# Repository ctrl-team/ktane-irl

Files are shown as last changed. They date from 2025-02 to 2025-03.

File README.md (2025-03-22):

# ktane-irl

## Overview
This project is a real-life adaptation of the game "Keep Talking and Nobody Explodes.".
Modules may use Arduino or different microcontrollers, with each module documented in its own directory.

## Features
* Real-life bomb-defusal gameplay
* Advanced component system

## Software Requirements
- Arduino IDE
- TFT_eSPI library (included in lib/)

## Installation

### 1. Clone the Repository
```sh
git clone https://github.com/ctrl-team/ktane-irl.git
cd ktane-irl
```
### 2. Configure TFT_eSPI
TFT_eSPI requires a proper `User_Setup_Select.h` configuration. Users must manually edit:
```sh
TFT_eSPI/User_Setup_Select.h
```
#### to include:
for main timer board
```cpp
#include "User_Setups/Setup304_RP2040_ILI9341_Waveshare_2_4"
```
for button module
```cpp
#include <User_Setups/Setup305_RP2040_GC9A01.h>
```

## License
This project is licensed under GNU General Public License v3.0. See the LICENSE file for details.

## Acknowledgments
- [TFT_eSPI by Bodmer](https://github.com/Bodmer/TFT_eSPI)
- [RPI Pico Schematic and footprint by ncarandini](https://github.com/ncarandini/KiCad-RP-Pico)

## Contributing
Feel free to submit pull requests or open issues for bug reports and feature requests.

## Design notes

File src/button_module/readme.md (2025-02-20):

# Button Module

Recreation of the Button module from "Keep Talking and Nobody Explodes". The module features a physical button with an RGB LED strip and follows the same rules as the original game.

## Hardware Requirements

* Arduino-compatible board 
* 1x Push button
* 1x Common anode RGB LED
* 3x 220Ω resistors
* Jumper wires
* Breadboard (optional)

## Pin Configuration

```
Button: GPIO15
RGB LED:
- Red: GPIO16
- Green: GPIO17
- Blue: GPIO18
```

## Wiring Diagram

```
Button:
- One pin to GPIO15
- Other pin to GND

RGB LED (Common Anode):
- Common pin to 3.3V/5V
- Red pin through 220Ω resistor to GPIO16
- Green pin through 220Ω resistor to GPIO17
- Blue pin through 220Ω resistor to GPIO18
```

## Features

* Real-time bomb timer countdown
* LED color feedback based on button state
* Strike system for incorrect inputs
* Serial monitor feedback for debugging
* Proper button debouncing
* Follows official KTANE rules for the Button module

## Game Rules

The module implements the following rules from the original game:

### Follow these rules in the order they are listed. Perform the first action that applies:

1. If the button is $${\color{#1589F0}Blue}$$ and the button says **"Abort"**, hold the button and refer
to "Releasing a Held Button".
2. If there is **more than 1 battery** on the bomb and the button says **"Detonate"**,
press and immediately release the button.
3. If the button is $${\color{#FFFFFF}White}$$ and there is a **lit indicator with label CAR**, hold the
button and refer to "Releasing a Held Button".
4. If there are **more than 2 batteries** on the bomb and there is a **lit indicator
with label FRK**, press and immediately release the button.
5. If the button is $${\color{#FFCC00}Yellow}$$, hold the button and refer to "Releasing a Held
Button".
6. If the button is $${\color{#FF0000}Red}$$ and the button says **"Hold"**, press and immediately
release the button.
7. If none of the above apply, hold the button and refer to "Releasing a Held
Button".

### Releasing a Held Button

If you start holding the button down, a colored strip will light up on the right
side of the module. Based on its color, you must release the button at a specific
point in time:
- $${\color{#1589F0}Blue}$$ strip: release when the countdown timer has a 4 in any position.
- $${\color{#FFFFFF}White}$$ strip: release when the countdown timer has a 1 in any position.
- $${\color{#FFCC00}Yellow}$$ strip: release when the countdown timer has a 5 in any position.
- Any other color strip: release when the countdown timer has a 1 in any
position.

## Configuration Variables

You can modify these variables at the top of the code to test different scenarios:

```cpp
bool hasBatteryMoreThan1 = true;   // More than 1 battery
bool hasBatteryMoreThan2 = false;  // More than 2 batteries
bool litCARIndicator = true;       // Lit CAR indicator
bool litFRKIndicator = false;      // Lit FRK indicator
String buttonLabel = "Abort";      // Button text
String buttonColor = "Blue";       // Button color
```

## Installation

1. Connect the hardware according to the pin configuration
2. Open the Arduino IDE
4. Upload the code to your board
5. Open Serial Monitor at 115200 baud to see debug information

## Serial Monitor Output

The Serial Monitor provides real-time feedback:
* Current timer value
* Button press and release events
* Module states (solved/strike)
* LED color changes

## Known Limitations FOR NOW

* Timer does not sync with other modules
* Mock values must be changed in code (no external inputs)
* No physical display for timer values

## Credits

Based on the Button module from "Keep Talking and Nobody Explodes" by Steel Crate Games.

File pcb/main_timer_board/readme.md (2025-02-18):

# Main Timer Module PCB

KiCad project for the Main Timer Module in a KTANE replica.

Raspberry Pi symbol & footprint sourced from [here](https://github.com/ncarandini/KiCad-RP-Pico).

# Files

📜 timer_board_schematic.kicad_sch - Schematic

🖼️ timer_board_schematic.kicad_pcb - PCB Layout

⚙️ timer_board_schematic.kicad_pro - Project Settings

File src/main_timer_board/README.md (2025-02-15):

# main_timer_board

The main timer board is the central controller for the game. It manages game time, connected modules, and overall game state. It also controls the main display and coordinates communication with all other modules using I2C.

This project uses the [**Waveshare 2.4" SPI ILI9341 LCD (model 18366)**](https://www.waveshare.com/2.4inch-lcd-module.htm). We provide a preconfigured header file for TFT_eSPI. If you are using the same screen, we highly recommend using our configuration to avoid display issues, the `Setup304_RP2040_ILI9341_Waveshare_2_4.h` configuration file is included in the `/include` directory. The correct display driver must be selected in the TFT_eSPI library.

## Wiring

Schematic_ktane_2025-02-15(1)

### Display

| **Display Pin** | **RP2040 Pin (TFT_eSPI Mapping)** |
|---|---|
| VCC | 3.3V |
| GND | GND |
| DIN | GPIO11 (`TFT_MOSI`) |
| CLK | GPIO10 (`TFT_SCLK`) |
| CS | GPIO9  (`TFT_CS`) |
| DC | GPIO8 (`TFT_DC`) |
| RST | GPIO12 (`TFT_SCLK`) |
| BL | 3.3V |

### Buzzer

This project uses a buzzer **without a built-in generator**, so it must be connected to a **PWM-capable pin**

All values are adjustable in code. You can adjust `BUZZER_INPUT` pin in `main_timer_board.ino`

| **Buzzer Pin** | **RP2040 Pin (TFT_eSPI Mapping)** |
|---|---|
| + | GPIO2 |
| - | GND |

### Buttons

All connected to common ground

| **Button** | **RP2040 Pin (TFT_eSPI Mapping)** |
|---|---|
| BACK | GPIO21 |
| ENTER | GPIO20 |
| BOTTOM | GPIO19 |
| TOP | GPIO18 |

## **Important Notice**

The **User_Setup_Select.h** file in the TFT_eSPI library must be modified to include the correct display configuration:

```cpp
#include "Setup304_RP2040_ILI9341_Waveshare_2_4.h"
```

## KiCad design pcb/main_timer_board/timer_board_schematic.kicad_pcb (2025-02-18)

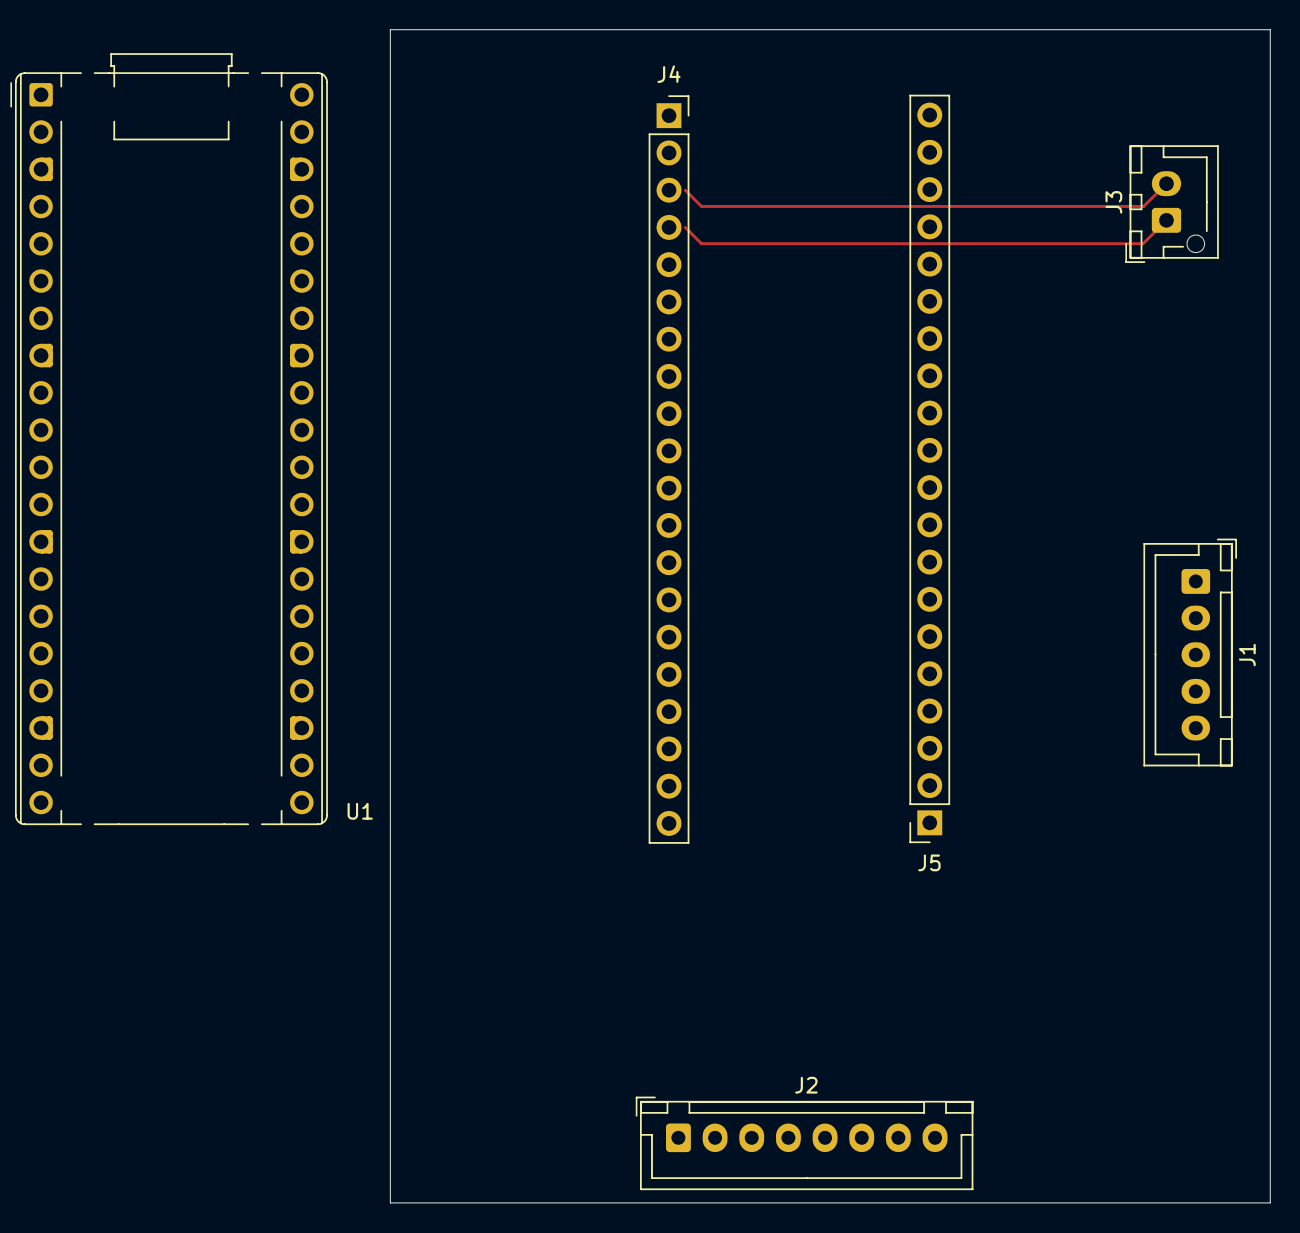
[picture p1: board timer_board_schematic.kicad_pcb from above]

Board: 2 copper layers, 60.0 x 80.0 mm, 6 parts (0 on the bottom side), 14 nets.

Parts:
J1: Buttons Socket; JST_XH_B5B-XH-A_1x05_P2.50mm_Vertical
J2: Screen Socket; JST_XH_B8B-XH-A_1x08_P2.50mm_Vertical
J3: Buzzer Socket; JST_XH_B2B-XH-AM_1x02_P2.50mm_Vertical
J4, J5: Conn_01x20_Socket; PinSocket_1x20_P2.54mm_Vertical
U1: Pico; RaspberryPi_Pico_Common_THT

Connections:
unnamed: J1.1, J5.7
unnamed: J1.2, J5.6
unnamed: J1.3, J5.5
unnamed: J1.4, J5.4
unnamed: J1.5, J5.3
unnamed: J2.1, J2.8, J5.16
unnamed: J2.2, J4.16
unnamed: J2.3, J4.11
unnamed: J2.4, J4.12
unnamed: J2.5, J4.14
unnamed: J2.6, J4.15
unnamed: J2.7, J5.18
unnamed: J3.1, J4.4
unnamed: J3.2, J4.3

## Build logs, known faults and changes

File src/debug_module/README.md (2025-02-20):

# debug_module

This module is only being used for debuging purposes. It uses two buttons connected to `GPIO16` for solving module and `GPIO17` for sending `STRIKE` state to main timer.

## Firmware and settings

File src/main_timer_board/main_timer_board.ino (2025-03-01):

#include "Arduino.h"
#include <TFT_eSPI.h>
#include <SPI.h>
#include "bus_controller.h"

// swapping width and height because the screen is used in landscape mode
#define LCD_HEIGHT TFT_WIDTH
#define LCD_WIDTH TFT_HEIGHT

// I/O definitions
#define TOP_BUTTON 18
#define BOTTOM_BUTTON 19
#define ENTER_BUTTON 20
#define BACK_BUTTON 21
#define BUZZER_PIN 2 // Buzzer + pin

enum Menus {
  NONE,
  MAIN_MENU,
  SETTINGS,
  SETTINGS_TIMER,
  SETTINGS_BATTERIES,
  SETTINGS_PORTS,
  SETTINGS_FLAGS,
  INFORMATION
};

TFT_eSPI tft = TFT_eSPI();
BusController controller;

bool rerender = true;
bool rerenderContent = true;
Menus openedMenu = MAIN_MENU;
int selectedItem = 0;

int batteries = 0;
int flags = 0;
int ports = 0;

// timing variables
int lastOpened = 0;
int intervalTime = 0;
int stateTimer = 0;

bool upPressed = false;
bool downPressed = false;
bool enterPressed = false;
bool backPressed = false;

bool justStarted = false;
uint16_t timer = 120; // just enough time for 18 hours gameplay
uint16_t defaultTimer = 300; // 5 minutes
int leftPadding = 2;

void renderTopBar() {
  tft.fillRect(0, 0, LCD_WIDTH, 20, TFT_RED);
  tft.setTextColor(TFT_WHITE);
  tft.setCursor(leftPadding, 2, 2);

  switch (openedMenu) {
    case MAIN_MENU:
      tft.println("Main menu");
      break;
    case SETTINGS:
      tft.println("Settings");
      break;
    case SETTINGS_TIMER:
      tft.println("Game time");
      break;
    case SETTINGS_BATTERIES:
      tft.println("Number of batteries");
      break;
    case SETTINGS_FLAGS:
      tft.println("Number of flags");
      break;
    case SETTINGS_PORTS:
      tft.println("Number of ports");
      break;
    case INFORMATION:
      tft.println("Information");
      break;
  }
}

void defaultBottomBar() {
  int x = tft.textWidth("F1 - UP");
  int y = tft.textWidth("F2 - DOWN");
  int z = tft.textWidth("F3 - ENTER");

  tft.print("F1 - UP");
  tft.setCursor(leftPadding * 3 + x, LCD_HEIGHT - 14);
  tft.print("F2 - DOWN");
  tft.setCursor(leftPadding * 5 + x + y, LCD_HEIGHT - 14);
  tft.print("F3 - ENTER");
  tft.setCursor(leftPadding * 7 + x + y + z, LCD_HEIGHT - 14);
  tft.setTextColor(openedMenu == MAIN_MENU ? controller.state == PAUSED ? TFT_WHITE : TFT_DARKGREY : TFT_WHITE);
  tft.print("F4 - BACK");
}

void renderBottomBar() {
  tft.fillRect(0, LCD_HEIGHT - 20, LCD_WIDTH, LCD_HEIGHT, TFT_RED);
  tft.setTextColor(TFT_WHITE);
  tft.setCursor(leftPadding, LCD_HEIGHT - 14, 1);

  if (openedMenu == MAIN_MENU) {
    switch (selectedItem) {
      case 1:
        tft.print("Change game behaviour");
        break;
      case 2:
        tft.print("Display connected modules");
        break;
      default: {
        defaultBottomBar();
        break;
      }
    }

    return;
  }

  if (
    openedMenu == SETTINGS_TIMER ||
    openedMenu == SETTINGS_BATTERIES ||
    openedMenu == SETTINGS_FLAGS ||
    openedMenu == SETTINGS_PORTS
  ) {
    tft.print("F1 +");
    tft.setCursor(leftPadding * 3 + tft.textWidth("F1 +"), LCD_HEIGHT - 14);
    tft.print("F2 -");
    tft.setCursor(leftPadding * 5 + tft.textWidth("F1 +") + tft.textWidth("F2 -"), LCD_HEIGHT - 14);
    tft.print("F3 - SAVE");

    return;
  }

  defaultBottomBar();
}

void renderContent() {
  tft.setCursor(leftPadding, 22, 2);

  if (openedMenu == MAIN_MENU) {
    tft.setTextColor(TFT_WHITE, selectedItem == 0 ? TFT_DARKGREEN : TFT_BLACK);
    tft.print(controller.state == PAUSED ? "End game" : "Start game");

    tft.setCursor(leftPadding, 22 + tft.fontHeight() + 4, 2);
    tft.setTextColor(controller.state == PAUSED ? TFT_DARKGREY : TFT_WHITE, selectedItem == 1 ? TFT_DARKGREEN : TFT_BLACK);
    tft.print("Settings");

    tft.setCursor(leftPadding, 22 + tft.fontHeight() * 2 + 8, 2);
    tft.setTextColor(controller.state == PAUSED ? TFT_DARKGREY : TFT_WHITE, selectedItem == 2 ? TFT_DARKGREEN : TFT_BLACK);
    tft.print("Information");
  }

  if (openedMenu == SETTINGS) {
    tft.setTextColor(TFT_WHITE, selectedItem == 0 ? TFT_DARKGREEN : TFT_BLACK);
    tft.print("Timer");

    tft.setCursor(leftPadding, 22 + tft.fontHeight() + 4, 2);
    tft.setTextColor(TFT_WHITE, selectedItem == 1 ? TFT_DARKGREEN : TFT_BLACK);
    tft.print("Batteries");

    tft.setCursor(leftPadding, 22 + tft.fontHeight() * 2 + 8, 2);
    tft.setTextColor(TFT_WHITE, selectedItem == 2 ? TFT_DARKGREEN : TFT_BLACK);
    tft.print("Flags");

    tft.setCursor(leftPadding, 22 + tft.fontHeight() * 3 + 12, 2);
    tft.setTextColor(TFT_WHITE, selectedItem == 3 ? TFT_DARKGREEN : TFT_BLACK);
    tft.print("Ports");

    tft.setCursor(leftPadding, 22 + tft.fontHeight() * 4 + 16, 2);
    tft.setTextColor(TFT_WHITE, selectedItem == 4 ? TFT_DARKGREEN : TFT_BLACK);
    tft.print("Randomize");
  }

  if (openedMenu == SETTINGS_TIMER) {
    char buffer[6];
    sprintf(buffer, "%02d:%02d", defaultTimer / 60, defaultTimer % 60);
    tft.setTextColor(TFT_WHITE, TFT_BLACK);
    tft.setTextFont(6);
    tft.setCursor((LCD_WIDTH / 2) - (tft.textWidth(buffer) / 2), (LCD_HEIGHT / 2) - (tft.fontHeight() / 2));
    tft.print(buffer);
  }

  if (openedMenu == SETTINGS_BATTERIES) {
    char buffer[3];
    sprintf(buffer, "%02d", batteries);
    tft.setTextColor(TFT_WHITE, TFT_BLACK);
    tft.setTextFont(6);
    tft.setCursor((LCD_WIDTH / 2) - (tft.textWidth(buffer) / 2), (LCD_HEIGHT / 2) - (tft.fontHeight() / 2));
    tft.print(buffer);
  }

  if (openedMenu == SETTINGS_FLAGS) {
    char buffer[3];
    sprintf(buffer, "%02d", flags);
    tft.setTextColor(TFT_WHITE, TFT_BLACK);
    tft.setTextFont(6);
    tft.setCursor((LCD_WIDTH / 2) - (tft.textWidth(buffer) / 2), (LCD_HEIGHT / 2) - (tft.fontHeight() / 2));
    tft.print(buffer);
  }

  if (openedMenu == SETTINGS_PORTS) {
    char buffer[2];
    sprintf(buffer, "%d", ports);
    tft.setTextColor(TFT_WHITE, TFT_BLACK);
    tft.setTextFont(6);
    tft.setCursor((LCD_WIDTH / 2) - (tft.textWidth(buffer) / 2), (LCD_HEIGHT / 2) - (tft.fontHeight() / 2));
    tft.print(buffer);
  }

  if (openedMenu == INFORMATION) {
    if (controller.modules == 0) {
      tft.setCursor((LCD_WIDTH / 2) - (tft.textWidth("NO MODULES FOUND") / 2), (LCD_HEIGHT / 2) - (tft.fontHeight() / 2));
      tft.setTextColor(TFT_WHITE);
      tft.print("NO MODULES FOUND");
      return;
    }

    // int padding = 1;

    // for (Module module : controller.modules) {
    //   tft.setCursor(leftPadding, 22 + tft.fontHeight() * padding + 2 * ++padding, 2);
    // }
  }
}

void render() {
  if (!rerender && !rerenderContent) return;

  if (rerender) {
    tft.fillScreen(TFT_BLACK);
    selectedItem = 0;
  }

  switch (openedMenu) {
    case NONE:
      char buffer[6];
      sprintf(buffer, "%02d:%02d", timer / 60, timer % 60);

      tft.setTextColor(TFT_RED, TFT_BLACK);
      tft.setTextFont(8);
      tft.setCursor((LCD_WIDTH / 2) - (tft.textWidth(buffer) / 2), (LCD_HEIGHT / 2) - (tft.fontHeight() / 2));
      tft.print(buffer);
      break;
    default:
      renderTopBar();
      renderContent();
      renderBottomBar();
      break;
  }

  rerender = false;
  rerenderContent = false;
}

void gameOver() {
  tft.fillScreen(TFT_BLACK);

  controller.updateState(NOT_STARTED);

  tone(BUZZER_PIN, 2000);
  delay(300);
  noTone(BUZZER_PIN);
  delay(100);
  tone(BUZZER_PIN, 2000);
  delay(300);
  noTone(BUZZER_PIN);
  delay(100);
  tone(BUZZER_PIN, 2000);
  delay(300);
  noTone(BUZZER_PIN);

  while (digitalRead(ENTER_BUTTON) == HIGH) {
    tft.setTextColor(TFT_RED);
    tft.setTextFont(2);
    tft.setCursor((LCD_WIDTH / 2) - (tft.textWidth("GAME OVER") / 2), (LCD_HEIGHT / 2) - (tft.fontHeight() / 2) - 20);
    tft.print("GAME OVER");
    tft.setCursor((LCD_WIDTH / 2) - (tft.textWidth("Press 'Enter' to continue", 1) / 2), (LCD_HEIGHT / 2) + (tft.fontHeight() / 2) + 2, 1);
    tft.setTextColor(TFT_WHITE);
    tft.print("Press 'Enter' to continue");
    delay(50);
  }

  controller.solved = 0;
  controller.strikes = 0;
  timer = 0;
  enterPressed = true;
  openedMenu = MAIN_MENU;
  rerender = true;
}

void gameWon() {
  tft.fillScreen(TFT_BLACK);

  tone(BUZZER_PIN, 2000);
  delay(300);
  noTone(BUZZER_PIN);
  delay(100);
  tone(BUZZER_PIN, 1500);
  delay(300);
  noTone(BUZZER_PIN);
  delay(100);
  tone(BUZZER_PIN, 1000);
  delay(300);
  noTone(BUZZER_PIN);

  while (digitalRead(ENTER_BUTTON) == HIGH) {
    tft.setTextColor(TFT_GREEN);
    tft.setTextFont(2);
    tft.setCursor((LCD_WIDTH / 2) - (tft.textWidth("GAME WON") / 2), (LCD_HEIGHT / 2) - (tft.fontHeight() / 2) - 20);
    tft.print("GAME WON");
    tft.setCursor((LCD_WIDTH / 2) - (tft.textWidth("Press 'Enter' to continue", 1) / 2), (LCD_HEIGHT / 2) + (tft.fontHeight() / 2) + 2, 1);
    tft.setTextColor(TFT_WHITE);
    tft.print("Press 'Enter' to continue");
    delay(50);
  }

  controller.updateState(NOT_STARTED);

  controller.solved = 0;
  controller.strikes = 0;
  timer = 0;
  enterPressed = true;
  openedMenu = MAIN_MENU;
  rerender = true;
}

void startGame() {
  controller.updateState(PLAYING);
  timer = defaultTimer;
  justStarted = true;

  openedMenu = NONE;
  rerender = true;

  randomSeed(analogRead(A0));

  controller.config.randomize(flags, ports, batteries);
  // Serial.print("Flags set: 0b");
  // Serial.println(controller.config.flags, BIN);
  // Serial.print("Ports set: 0b");
  // Serial.println(controller.config.ports, BIN);
  // Serial.print("Serial number: ");
  // Serial.println(controller.config.serial);

  controller.sendConfiguration();

  tft.setTextColor(TFT_WHITE, TFT_BLACK);
  tft.setTextFont(8);
  tft.setCursor((LCD_WIDTH / 2) - (tft.textWidth("321") / 2), (LCD_HEIGHT / 2) - (tft.fontHeight() / 2));
  tft.fillScreen(TFT_BLACK);

  tft.print("3");
  tone(BUZZER_PIN, 1000, 100);
  delay(900);

  tft.print("2");
  tone(BUZZER_PIN, 1500, 100);
  delay(900);

  tft.print("1");
  tone(BUZZER_PIN, 2000, 100);
  delay(900);
}

void handleButtons() {
  bool upState = digitalRead(TOP_BUTTON) == LOW;
  bool downState = digitalRead(BOTTOM_BUTTON) == LOW;
  bool enterState = digitalRead(ENTER_BUTTON) == LOW;
  bool backState = digitalRead(BACK_BUTTON) == LOW;

  if (upState && !upPressed) {
    tone(BUZZER_PIN, 1000, 50);

    if (openedMenu == MAIN_MENU)
      selectedItem = (selectedItem == 0) ? 2 : selectedItem - 1;

    if (openedMenu == SETTINGS)
      selectedItem = (selectedItem == 0) ? 4 : selectedItem - 1;

    if (openedMenu == SETTINGS_TIMER)
      defaultTimer++;

    if (openedMenu == SETTINGS_BATTERIES)
      batteries <= 10 && batteries++;

    if (openedMenu == SETTINGS_FLAGS)
      flags <= 11 && flags++;

    if (openedMenu == SETTINGS_PORTS)
      ports <= 6 && ports++;

    rerenderContent = true;
  }

  if (downState && !downPressed) {
    tone(BUZZER_PIN, 1000, 50);

    if (openedMenu == MAIN_MENU)
      selectedItem = ++selectedItem % 3;
    
    if (openedMenu == SETTINGS)
      selectedItem = ++selectedItem % 5;

    if (openedMenu == SETTINGS_TIMER)
      defaultTimer > 0 && defaultTimer--;

    if (openedMenu == SETTINGS_BATTERIES)
      batteries > 0 && batteries--;

    if (openedMenu == SETTINGS_FLAGS)
      flags > 0 && flags--;

    if (openedMenu == SETTINGS_PORTS)
      ports > 0 && ports--;

    rerenderContent = true;
  }

  if (enterState && !enterPressed) {
    if (openedMenu != MAIN_MENU || (openedMenu == MAIN_MENU && (controller.state != PLAYING && selectedItem != 0))) {
      tone(BUZZER_PIN, 1000, 50);
    }

    if (openedMenu == MAIN_MENU && !rerender) {
      switch (selectedItem) {
        case 0:
          if (controller.state == PAUSED)
            gameOver();
          else
            startGame();
          break;
        case 1:
          openedMenu = SETTINGS;
          rerender = true;
          break;
        case 2:
          openedMenu = INFORMATION;
          rerender = true;
          break;
      }
    }

    if (openedMenu == SETTINGS && !rerender) {
      switch (selectedItem) {
        case 0:
          openedMenu = SETTINGS_TIMER;
          rerender = true;
          break;
        case 1:
          openedMenu = SETTINGS_BATTERIES;
          rerender = true;
          break;
        case 2:
          openedMenu = SETTINGS_FLAGS;
          rerender = true;
          break;
        case 3:
          openedMenu = SETTINGS_PORTS;
          rerender = true;
          break;
        case 4:
          randomSeed(analogRead(A1));
          batteries = random(0, 10);
          flags = random(0, 11);
          ports = random(0, 6);
          break;
      }
    }
    
    if (
      (openedMenu == SETTINGS_TIMER ||
      openedMenu == SETTINGS_BATTERIES ||
      openedMenu == SETTINGS_FLAGS ||
      openedMenu == SETTINGS_PORTS) && !rerender
    ) {
      openedMenu = SETTINGS;
      rerender = true;
    }

    if (openedMenu == NONE && !rerender) {
      controller.updateState(PAUSED);
      openedMenu = MAIN_MENU;
      rerender = true;
      lastOpened = millis();
    }
  }

  if (backState && !backPressed) {
    tone(BUZZER_PIN, 1000, 50);

    if (openedMenu == MAIN_MENU && controller.state == PAUSED && !rerender) {
      controller.updateState(PLAYING);

      openedMenu = NONE;
      rerender = true;
    }

    if (openedMenu == SETTINGS || openedMenu == INFORMATION && !rerender) {
      openedMenu = MAIN_MENU;
      rerender = true;
    }
  }

  upPressed = upState;
  downPressed = downState;
  enterPressed = enterState;
  backPressed = backState;
}

void gameLogic() {
  int currentTime = millis();

  if (openedMenu != NONE && currentTime - lastOpened >= 10000) {
    controller.updateState(PLAYING);

    lastOpened = 0;
    openedMenu = NONE;
    rerender = true;
  }

  if (openedMenu == NONE && currentTime - intervalTime >= 1000) {
    timer--;

    controller.updateTimer(timer);

    intervalTime = millis();
    rerenderContent = true;

    if (timer <= 5)
      tone(BUZZER_PIN, 1000 + 100 * (5 - timer), 50);

    if (timer <= 0) gameOver();
  }

  if (controller.strikes > 2)
    gameOver();

  if (controller.solved >= controller.moduleCount)
    gameWon();
}

void setup() {
  delay(1000); // necessary, serial seems to break without it

  Serial.begin(115200);
  Serial.flush();

  tft.init();
  tft.setRotation(3);

  controller.begin();

  pinMode(TOP_BUTTON, INPUT_PULLUP);
  pinMode(BOTTOM_BUTTON, INPUT_PULLUP);
  pinMode(ENTER_BUTTON, INPUT_PULLUP);
  pinMode(BACK_BUTTON, INPUT_PULLUP);
  pinMode(BUZZER_PIN, OUTPUT);
  pinMode(LED_BUILTIN, OUTPUT);

  rerender = true;
}

void loop() {
  int currentTime = millis();

  handleButtons();

  if (justStarted) {
    justStarted = false;

    tone(BUZZER_PIN, 1000);
    delay(50);
    tone(BUZZER_PIN, 1500);
    delay(50);
    tone(BUZZER_PIN, 2000);
    delay(50);
    noTone(BUZZER_PIN);
  }

  if (currentTime - stateTimer > 100) {
    stateTimer = millis();
    controller.refreshStates();

    if (controller.justStriked) {
      tone(BUZZER_PIN, 800, 500);

      Serial.print("[lo] strike: ");
      Serial.println(controller.strikes);
    }

    if (controller.justSolved) {
      tone(BUZZER_PIN, 1000);
      delay(50);
      tone(BUZZER_PIN, 1500);
      delay(50);
      tone(BUZZER_PIN, 2000);
      delay(50);
      noTone(BUZZER_PIN);

      Serial.print("[lo] solved: ");
      Serial.println(controller.solved);
    }
  }

  if (controller.state == PLAYING) gameLogic();

  render();
}

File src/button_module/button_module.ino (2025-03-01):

#include <Arduino.h>
#include <Wire.h>

#include "bus_receiver.h"

#define RGB_COMMON_ANODE // affects all diodes

#define BUTTON_PIN 15  // Button connected to GPIO15
#define HOLD_TIME 1500  // Hold time in milliseconds 
#define DEBOUNCE_DELAY 50  // Debounce delay in milliseconds

// RGB STATE LED Pins
#define STATE_RED_PIN 19
#define STATE_GREEN_PIN 20
#define STATE_BLUE_PIN 21

// RGB STRIP LED Pins
#define STRIP_RED_PIN 16
#define STRIP_GREEN_PIN 17
#define STRIP_BLUE_PIN 18

enum ButtonLabel {
  ABORT = 0,
  DETONATE = 1,
  HOLD = 2
};

enum Color {
  BLUE = 0,
  WHITE = 1,
  YELLOW = 2,
  RED = 3,
  GREEN = 4,
  MAGENTA = 5,
  CYAN = 6
};

BusReceiver receiver;

uint16_t lastPressTime = 0;  // Time of last button press
uint16_t pressTime = 0;  // Time the button was pressed
uint16_t lastHoldCheck = 0;  // Time of last hold check
uint16_t duration = 0;  // Duration of the press

// Example mock values (replace with actual logic to read these values)
ButtonLabel buttonLabel = ABORT;  // Button label ("Abort", "Detonate", etc.)
Color buttonColor = BLUE;  // Button color ("Blue", "White", "Yellow", "Red")
Color stripColor = BLUE;

// Variables to track button state
bool buttonPressed = false;
bool previousButtonState = HIGH;
bool isHolding = false;  // Track if button is being held

void setLEDColor(int redPin, int greenPin, int bluePin, int red, int green, int blue) {
  #ifdef RGB_COMMON_ANODE
    digitalWrite(redPin, !red);
    digitalWrite(greenPin, !green);
    digitalWrite(bluePin, !blue);
  #else
    digitalWrite(redPin, red);
    digitalWrite(greenPin, green);
    digitalWrite(bluePin, blue);
  #endif
}

void setStateColor(int red, int green, int blue) {
  setLEDColor(STATE_RED_PIN, STATE_GREEN_PIN, STATE_BLUE_PIN, red, green, blue);
}

void setStripColor(int red, int green, int blue) {
  setLEDColor(STRIP_RED_PIN, STRIP_GREEN_PIN, STRIP_BLUE_PIN, red, green, blue);
}

bool hasDigitInTimer(int digit) {
  int mins = receiver.timer / 60;
  int secs = receiver.timer % 60;

  return (secs % 10 == digit) ||
         ((secs / 10) % 10 == digit) ||
         (mins % 10 == digit) ||
         ((mins / 10) % 10 == digit);
}

bool shouldPressAndRelease() {
  return (receiver.config.batteries == 1 && buttonLabel == DETONATE) ||
         (receiver.config.batteries >= 2 && receiver.config.hasFlag(FRK)) ||
         (buttonColor == RED && buttonLabel == HOLD);
}

void processButtonRelease() {
  if (shouldPressAndRelease()) {
    if (duration < HOLD_TIME) {
      Serial.println("Module solved! Correct quick press.");
      receiver.state = SOLVED;
    }
  } else {
    if (duration >= HOLD_TIME) {
      bool correctRelease = false;
      
      if (stripColor == BLUE) {
        correctRelease = hasDigitInTimer(4);
      } else if (stripColor == YELLOW) {
        correctRelease = hasDigitInTimer(5);
      } else {
        correctRelease = hasDigitInTimer(1);
      }
      
      if (correctRelease) {
        Serial.println("Module solved! Correct hold and release.");
        receiver.state = SOLVED;
      } else {
        Serial.println("Strike! Released on wrong number.");
        receiver.state = STRIKE;
      }
    } else {
      Serial.println("Strike! Button wasn't held long enough.");
      receiver.state = STRIKE;
    }
  }

  setStripColor(LOW, LOW, LOW);
}

void handleHoldingSequence() {
  switch (stripColor) {
    case BLUE:
      setStripColor(LOW, LOW, HIGH);
      break;
    case WHITE:
      setStripColor(HIGH, HIGH, HIGH);
      break;
    case YELLOW:
      setStripColor(HIGH, HIGH, LOW);
      break;
    case RED:
      setStripColor(HIGH, LOW, LOW);
      break;
    case GREEN:
      setStripColor(LOW, HIGH, LOW);
      break;
    case MAGENTA:
      setStripColor(HIGH, LOW, HIGH);
      break;
    case CYAN:
      setStripColor(LOW, HIGH, HIGH);
      break;
  }

  Serial.print("LED strip color: ");
  Serial.println(stripColor);
}

void handleButton() {
  bool currentButtonState = digitalRead(BUTTON_PIN);
  uint16_t currentTime = millis();

  // Button press handling
  if (currentButtonState == LOW && previousButtonState == HIGH) {
    if (currentTime - lastPressTime > DEBOUNCE_DELAY) {
      buttonPressed = true;
      isHolding = false;
      pressTime = currentTime;
      lastHoldCheck = currentTime;
      Serial.println("Button pressed!");
    }
  }
  
  // Continuous hold checking
  if (buttonPressed && currentButtonState == LOW) {
    duration = currentTime - pressTime;
    
    // Check for hold duration every 100ms
    if (currentTime - lastHoldCheck >= 100) {
      lastHoldCheck = currentTime;
      
      if (shouldPressAndRelease() && duration >= HOLD_TIME) {
        Serial.println("Strike! Held when should have been quick press");
        receiver.state = STRIKE;
        buttonPressed = false;  // Reset button state after strike
      } else if (!shouldPressAndRelease() && !isHolding && duration >= HOLD_TIME) {
        handleHoldingSequence();
        isHolding = true;
        Serial.println("Hold threshold reached");
      }
    }
  }
  
  // Button release handling
  if (currentButtonState == HIGH && previousButtonState == LOW) {
    if (buttonPressed) {
      duration = currentTime - pressTime;
      buttonPressed = false;
      processButtonRelease();
    }
  }

  previousButtonState = currentButtonState;
}

void setup() {
  delay(1000);

  Serial.begin(115200);
  Serial.flush();

  receiver.begin(BUTTON_MODULE);

  pinMode(BUTTON_PIN, INPUT_PULLUP);
  pinMode(STATE_RED_PIN, OUTPUT);
  pinMode(STATE_GREEN_PIN, OUTPUT);
  pinMode(STATE_BLUE_PIN, OUTPUT);
  pinMode(STRIP_RED_PIN, OUTPUT);
  pinMode(STRIP_GREEN_PIN, OUTPUT);
  pinMode(STRIP_BLUE_PIN, OUTPUT);

  setStateColor(LOW, LOW, LOW);
  setStripColor(LOW, LOW, LOW);

  Serial.print("Module 0x");
  Serial.print(receiver.moduleAddress, HEX);
  Serial.println(" initialized");
}

void loop() {
  if (receiver.justStarted) {
    randomSeed(analogRead(A1));

    receiver.justStarted = false;
    buttonLabel = static_cast<ButtonLabel>(random(3));
    buttonColor = static_cast<Color>(random(4));
    stripColor = static_cast<Color>(random(7));

    Serial.println("New game started!");
    Serial.print("Button label: ");
    Serial.println(buttonLabel);
    Serial.print("Button color: ");
    Serial.println(buttonColor);
    Serial.print("Strip color: ");
    Serial.println(stripColor);
    Serial.print("FRK: ");
    Serial.println(receiver.config.hasFlag(FRK) ? "yes" : "no");
    Serial.print("Batteries: ");
    Serial.println(receiver.config.batteries);
  }

  if (receiver.state == PLAYING)
    handleButton();

  switch (receiver.state) {
    case SOLVED:
      setStateColor(LOW, HIGH, LOW);
      break;
    case STRIKE:
      setStateColor(HIGH, LOW, LOW);
      break;
    default:
      setStateColor(LOW, LOW, LOW);
  }

  while (receiver.state == STRIKE || receiver.state == SOLVED) {
    delay(500);
  }
}

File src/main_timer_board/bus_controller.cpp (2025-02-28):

#include "bus_controller.h"


ModuleType BusController::whoAreYou(uint8_t targetAddress) {
  if (sendPacket(targetAddress, 0x04))
    return static_cast<ModuleType>(receiveByte(targetAddress));
  return MODULE_UNKNOWN;
}

ModuleState BusController::getState(uint8_t targetAddress) {
  if (sendPacket(targetAddress, 0x02))
    return static_cast<ModuleState>(receiveByte(targetAddress));
  return STATE_UNKNOWN;
}

void BusController::refreshStates() {
  justStriked = false;
  justSolved = false;

  for (int module = START_ADDRESS; module < END_ADDRESS; module++) {
    if (!modules[module].active) continue;

    ModuleState moduleState = getState(modules[module].id);
    if (moduleState == STATE_UNKNOWN) continue;

    if (moduleState == STRIKE) {
      justStriked = true;
      strikes++;
    }

    if (modules[module].state != SOLVED && moduleState == SOLVED) {
      justSolved = true;
      solved++;
    }

    modules[module].state = moduleState;

    Serial.print("[rs] Address 0x");
    Serial.print(modules[module].id, HEX);
    Serial.print(" state is 0x");
    Serial.println(modules[module].state, HEX);
  }
}

void BusController::initializeDevices() {
  moduleCount = 0;

  for (int module = START_ADDRESS; module < END_ADDRESS; module++) {
    Serial.print("[id] Scanning address 0x");
    Serial.println(module, HEX);

    if (!checkAddressAvailability(module)) {
      Serial.print("[id] Skipping address 0x");
      Serial.println(module, HEX);
      continue;
    }

    modules[module].id = module;
    modules[module].type = MODULE_UNKNOWN;
    modules[module].active = false;

    ModuleType moduleType = whoAreYou(module);
    if (moduleType == MODULE_UNKNOWN) continue;

    modules[module].type = moduleType;
    modules[module].active = true;

    ModuleState moduleState = getState(module);
    if (moduleState == STATE_UNKNOWN) continue;

    modules[module].state = moduleState;

    moduleCount++;

    Serial.print("[id] Address 0x");
    Serial.print(module, HEX);
    Serial.print(" identified itself as type 0x");
    Serial.println(moduleType, HEX);
  }
}

void BusController::updateState(ModuleState state) {
  this->state = state;
  broadcastPacket(0x1, state);
}

void BusController::updateTimer(uint16_t timer) {
  broadcastPacket(0x3, timer);
}

void BusController::sendConfiguration() {
  broadcastPacket(0x5, config.flags);
  broadcastPacket(0x6, config.ports);
  broadcastPacket(0x7, config.serial, sizeof(config.serial));
  broadcastPacket(0x8, config.batteries);
}

void BusController::begin() {
  Wire.setSDA(SDA_PIN);
  Wire.setSCL(SCL_PIN);
  Wire.begin();

  state = NOT_STARTED;
  strikes = 0;
  solved = 0;

  initializeDevices();

  for (auto module : modules) {
    Serial.print("Module at address 0x");
    Serial.print(module.id, HEX);
    Serial.print(" is ");
    Serial.println(module.active ? "online" : "offline");
  }

  broadcastPacket(0x1, state);
}

bool BusController::checkAddressAvailability(uint8_t address) {
  Wire.beginTransmission(address);
  return (Wire.endTransmission() == 0);
}

uint8_t BusController::receiveByte(uint8_t targetAddress) {
  Wire.requestFrom(targetAddress, 1);

  uint32_t startTime = millis();
  while (!Wire.available()) {
    // 80ms timeout
    if (millis() - startTime > 80) {
      Serial.print("Timeout waiting for response from 0x");
      Serial.println(targetAddress, HEX);
      return 0xF;
    }
    delay(1); // allow CPU time for other tasks
  }

  return Wire.read();
}

bool BusController::sendPacket(uint8_t targetAddress, uint8_t command) {
  Wire.beginTransmission(targetAddress);
  Wire.write(command);

  // non-zero means error
  if (Wire.endTransmission() != 0) {
    Serial.print("Failed to send 0x");
    Serial.print(command, HEX);
    Serial.print(" request to address 0x");
    Serial.println(targetAddress, HEX);
    return false;
  }

  return true;
}

bool BusController::sendPacket(uint8_t targetAddress, uint8_t command, uint16_t data) {
  Wire.beginTransmission(targetAddress);
  Wire.write(command);
  Wire.write((uint8_t)(data >> 8)); // high byte
  Wire.write((uint8_t)(data & 0xFF)); // low byte

  // non-zero means error
  if (Wire.endTransmission() != 0) {
    Serial.print("Failed to send 0x");
    Serial.print(command, HEX);
    Serial.print(" with data 0x");
    Serial.print(data, HEX);
    Serial.print(" to address 0x");
    Serial.println(targetAddress, HEX);
    return false;
  }

  return true;
}

bool BusController::sendPacket(uint8_t targetAddress, uint8_t command, char* data, size_t length) {
  Wire.beginTransmission(targetAddress);
  Wire.write(command);

  Wire.write((const uint8_t*)data, length);

  // non-zero means error
  if (Wire.endTransmission() != 0) {
    Serial.print("Failed to send command 0x");
    Serial.print(command, HEX);
    Serial.print(" with data \"");
    Serial.print(data);
    Serial.print("\" to address 0x");
    Serial.println(targetAddress, HEX);
    return false;
  }

  return true;
}

void BusController::broadcastPacket(uint8_t command, uint16_t data) {
  for (int module = START_ADDRESS; module < END_ADDRESS; module++) {
    if (!checkAddressAvailability(module)) continue;
    sendPacket(module, command, data);
  }
}

void BusController::broadcastPacket(uint8_t command, char* data, size_t length) {
  for (int module = START_ADDRESS; module < END_ADDRESS; module++) {
    if (!checkAddressAvailability(module)) continue;
    sendPacket(module, command, data, length);
  }
}

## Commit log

2025-02-13 Use new display driver
2025-02-13 Fix button double-clicking, implement buzzer effects
    [main_timer_board.ino]
2025-02-14 fix negative time and rotate screen
    [main_timer_board.ino]
2025-02-14 UP BUTTON
    bug: when "start game" is selected, and up button is pressed, the selection wont skip to "information"
    [main_timer_board.ino]
2025-02-14 up button working
2025-02-15 Update README.md
    Diagram, and button pins
2025-02-15 Fix buttons
2025-02-16 test controller and board - i2c bus
2025-02-16 fixed invalid handling of requests
    [test_board.ino]
2025-02-16 Add timeout handling for I2C communication
    - Implemented a 80ms timeout in `receive_byte()` to prevent infinite waiting if a module does not respond.
    - Added error detection in `send_request()` to log failed transmissions.
    - Introduced a small delay in `initialize_devices()` to reduce I2C bus congestion.
    - Improved overall stability and reliability of module detection.
    [test_board.ino]
2025-02-17 implement packet broadcast, broadcast timer to modules
2025-02-17 add RGB diode
2025-02-18 main timer board pcb files
    [timer_board_schematic.kicad_pcb, timer_board_schematic.kicad_sch]
2025-02-18 gitignore kicad lock files
2025-02-19 detecting press and hold of a button
2025-02-19 Basic button logic
2025-02-20 Bug fixes
    - Fixed the timer digit checking:
    Checks tens and ones digits for both minutes and seconds
    For example, will now correctly detect "4" in times like 4:51, 1:40, 0:14
    - Fixed the press/hold logic:
    For cases that require immediate press (like batteries + FRK), now strictly checks that the duration was less than HOLD_TIME
    Gives strike if holding when should press immediately
    - Added random strip color generation:
    Strip color is determined when hold begins, not based on button color
    [button_module.ino]
2025-02-20 replace tabs with spaces
    [button_module.ino]
2025-02-20 Replace streak with strike oops
    [button_module.ino, debug_module.ino, main_timer_board.ino]
2025-02-20 Restore removed game logic (by mistake)
    [button_module.ino]
2025-02-20 Major changes
    - refactor to snakeCase
    - implement `0x1` command for updating module state
    - fix typo in `UNKOWN_STATE` -> `UNKNOWN_STATE`
    - fix few mistakes in `button_module` such as missing `static_cast`
    [bus_controller.cpp, button_module.ino, debug_module.ino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]
2025-02-20 implement i2c_receiver
2025-02-21 Few bux fixes - Implement checking if BUS device is available - Fixed unfinished IF statement - broadcast NOT_STARTED by default - Fixed game over menu
    [bus_controller.cpp, button_module.ino, main_timer_board.ino]
2025-02-22 Remove i2c_receiver
2025-02-28 Add `justStarted` flag to BusReceiver and update button randomization logic
2025-03-22 Driver for button module's round display
2025-03-22 Button screen driver
